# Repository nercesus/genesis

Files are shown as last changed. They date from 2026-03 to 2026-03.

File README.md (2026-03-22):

# Genesis
A 65% keyboard pcb with support for the [C3, C4, and S1 unified daughterboards](https://unified-daughterboard.github.io/).  
It also uses the [bakeneko65's](https://github.com/kkatano/bakeneko-65) outline, but don't expect it to be 100% compatible.  
This project was made back in 2022 using an older KiCad version, so some issues may come up when using a modern version.  

# layout
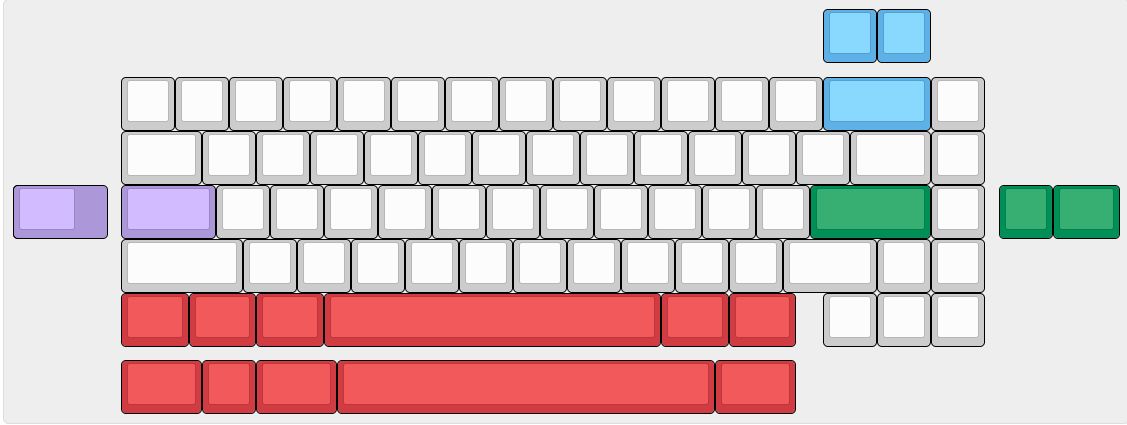
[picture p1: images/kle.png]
kle


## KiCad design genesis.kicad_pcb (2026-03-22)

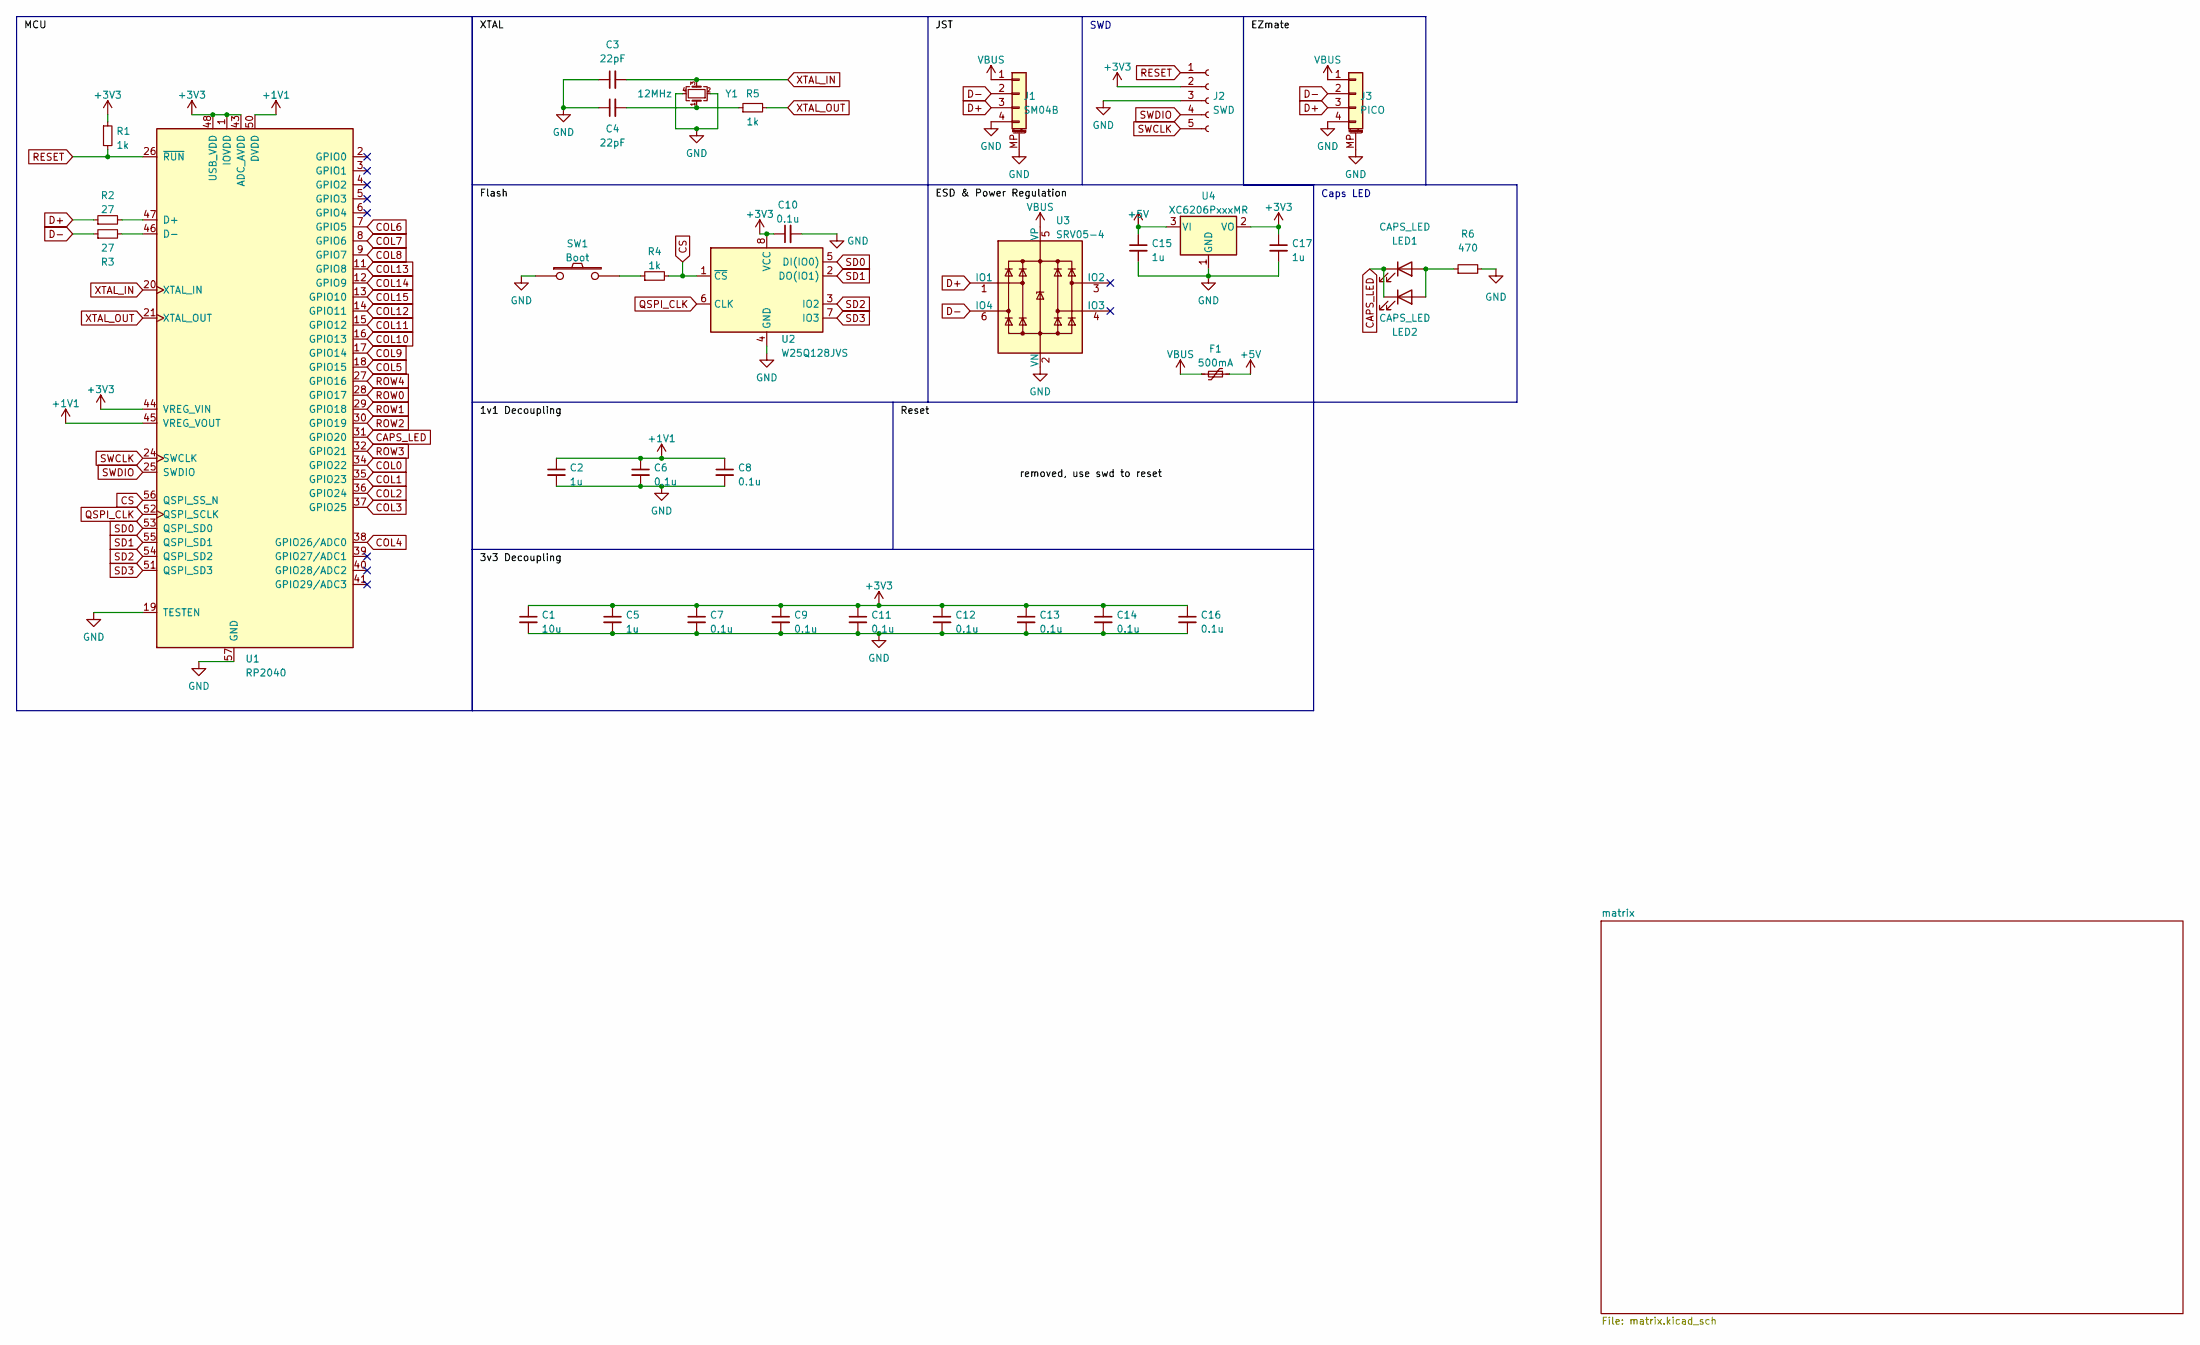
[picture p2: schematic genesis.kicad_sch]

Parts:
C1: 10u; C_0402_1005Metric
C2, C5, C15, C17: 1u; C_0402_1005Metric
C3, C4: 22pF; C_0402_1005Metric
C6, C7, C8, C9, C10, C11, C12, C13, C14, C16: 0.1u; C_0402_1005Metric
F1: 500mA; Fuse_1206_3216Metric
J1: SM04B; JST_SH_SM04B-SRSS-TB_1x04-1MP_P1.00mm_Horizontal
J2: SWD; PinSocket_1x05_P2.54mm_Vertical
J3: PICO; Molex_Pico-EZmate_78171-0004_1x04-1MP_P1.20mm_Vertical
LED1: CAPS_LED; MX-LEDONLY
LED2: CAPS_LED; MX-LEDONLY-FLIPPED
R1, R4, R5: 1k; R_0402_1005Metric
R2, R3: 27; R_0603_1608Metric
R6: 470; R_0402_1005Metric
SW1: Boot; PinHeader_1x02_P2.54mm_Vertical
U1: RP2040; RP2040-QFN-56; LCSC C2040
U2: W25Q128JVS; SOIC-8_5.23x5.23mm_P1.27mm
U3: SRV05-4; SOT-23-6-routable
U4: XC6206PxxxMR; SOT-23
Y1: 12MHz; Crystal_SMD_3225-4Pin_3.2x2.5mm

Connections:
+1V1: C2.1, C6.1, C8.1, U1.23 (DVDD), U1.45 (VREG_VOUT), U1.50 (DVDD)
+3V3: C1.1, C5.1, C7.1, C9.1, C10.1, C11.1, C12.1, C13.1, C14.1, C16.1, C17.1, J2.2, R1.1, U1.1 (IOVDD), U1.10 (IOVDD), U1.22 (IOVDD), U1.33 (IOVDD), U1.42 (IOVDD), U1.43 (ADC_AVDD), U1.44 (VREG_VIN), U1.48 (USB_VDD), U1.49 (IOVDD), U2.8 (VCC), U4.2 (VO)
+5V: C15.1, F1.1, U4.3 (VI)
CAPS_LED: LED1.1 (K), LED2.1 (K), U1.31 (GPIO20)
COL0: U1.34 (GPIO22); also elsewhere on the board
COL1: U1.35 (GPIO23); also elsewhere on the board
COL2: U1.36 (GPIO24); also elsewhere on the board
COL3: U1.37 (GPIO25); also elsewhere on the board
COL4: U1.38 (GPIO26/ADC0); also elsewhere on the board
COL5: U1.18 (GPIO15); also elsewhere on the board
COL6: U1.7 (GPIO5); also elsewhere on the board
COL7: U1.8 (GPIO6); also elsewhere on the board
COL8: U1.9 (GPIO7); also elsewhere on the board
COL9: U1.17 (GPIO14); also elsewhere on the board
COL10: U1.16 (GPIO13); also elsewhere on the board
COL11: U1.15 (GPIO12); also elsewhere on the board
COL12: U1.14 (GPIO11); also elsewhere on the board
COL13: U1.11 (GPIO8); also elsewhere on the board
COL14: U1.12 (GPIO9); also elsewhere on the board
COL15: U1.13 (GPIO10); also elsewhere on the board
CS: R4.2, U1.56 (QSPI_SS_N), U2.1 (~CS)
D+: J1.3, J3.3, R2.1, U3.1 (IO1)
D-: J1.2, J3.2, R3.1, U3.6 (IO4)
GND: C1.2, C2.2, C3.1, C4.1, C5.2, C6.2, C7.2, C8.2, C9.2, C10.2, C11.2, C12.2, C13.2, C14.2, C15.2, C16.2, C17.2, J1.4, J1.MP (MountPin), J2.3, J3.4, J3.MP (MountPin), R6.2, SW1.1, U1.19 (TESTEN), U1.57 (GND), U2.4 (GND), U3.2 (VN), U4.1 (GND), Y1.2, Y1.4
unnamed: C4.2, R5.1, Y1.1
unnamed: LED1.2 (A), LED2.2 (A), R6.1
unnamed: R2.2, U1.47 (D+)
unnamed: R3.2, U1.46 (D-)
unnamed: R4.1, SW1.2
QSPI_CLK: U1.52 (QSPI_SCLK), U2.6 (CLK)
RESET: J2.1, R1.2, U1.26 (~RUN)
ROW0: U1.28 (GPIO17); also elsewhere on the board
ROW1: U1.29 (GPIO18); also elsewhere on the board
ROW2: U1.30 (GPIO19); also elsewhere on the board
ROW3: U1.32 (GPIO21); also elsewhere on the board
ROW4: U1.27 (GPIO16); also elsewhere on the board
SD0: U1.53 (QSPI_SD0), U2.5 (DI(IO0))
SD1: U1.55 (QSPI_SD1), U2.2 (DO(IO1))
SD2: U1.54 (QSPI_SD2), U2.3 (IO2)
SD3: U1.51 (QSPI_SD3), U2.7 (IO3)
SWCLK: J2.5, U1.24 (SWCLK)
SWDIO: J2.4, U1.25 (SWDIO)
VBUS: F1.2, J1.1, J3.1, U3.5 (VP)
XTAL_IN: C3.2, U1.20 (XTAL_IN), Y1.3
XTAL_OUT: R5.2, U1.21 (XTAL_OUT)

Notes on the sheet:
SWD
Caps LED

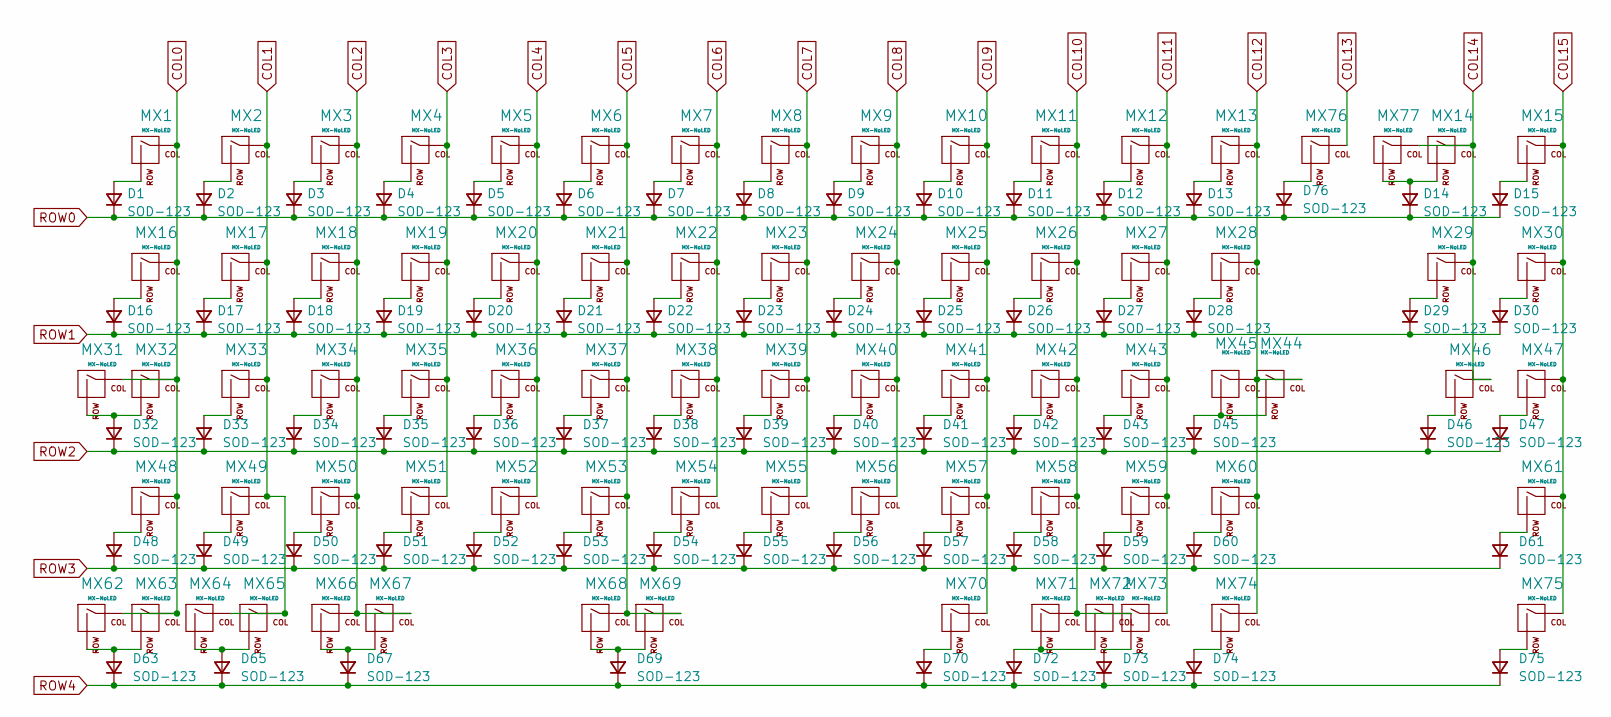
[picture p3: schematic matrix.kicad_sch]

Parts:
D1, D2, D3, D4, D5, D6, D7, D8, D9, D10, D11, D12, D13, D14, D15, D16, D17, D18, D19, D20, D21, D22, D23, D24, D25, D26, D27, D28, D29, D30, D32, D33, D34, D35, D36, D37, D38, D39, D40, D41, D42, D43, D45, D46, D47, D48, D49, D50, D51, D52, D53, D54, D55, D56, D57, D58, D59, D60, D61, D63, D65, D67, D69, D70, D72, D73, D74, D75, D76: SOD-123; D_SOD-123; LCSC C33221
MX1, MX2, MX3, MX4, MX5, MX6, MX7, MX8, MX9, MX10, MX11, MX12, MX13, MX15, MX17, MX18, MX19, MX20, MX21, MX22, MX23, MX24, MX25, MX26, MX27, MX28, MX30, MX33, MX34, MX35, MX36, MX37, MX38, MX39, MX40, MX41, MX42, MX43, MX44, MX47, MX49, MX50, MX51, MX52, MX53, MX54, MX55, MX56, MX57, MX58, MX60, MX61, MX65, MX73, MX74, MX75, MX76, MX77: MX-NoLED; MXOnly-1U-NoLED
MX14: MX-NoLED; MXOnly-2U-NoLED
MX16, MX29, MX63, MX67, MX71: MX-NoLED; MXOnly-1.5U-NoLED
MX31, MX46, MX62, MX64, MX66, MX70, MX72: MX-NoLED; MXOnly-1.25U-NoLED
MX32, MX59: MX-NoLED; MXOnly-1.75U-NoLED
MX45, MX48: MX-NoLED; MXOnly-2.25U-NoLED
MX68: MX-NoLED; MXOnly-6.25U-ReversedStabilizers-NoLED
MX69: MX-NoLED; MXOnly-7U-ReversedStabilizers-NoLED

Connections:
COL0: MX1.1 (COL), MX16.1 (COL), MX31.1 (COL), MX32.1 (COL), MX48.1 (COL), MX62.1 (COL), MX63.1 (COL); also elsewhere on the board
COL1: MX2.1 (COL), MX17.1 (COL), MX33.1 (COL), MX49.1 (COL), MX64.1 (COL), MX65.1 (COL); also elsewhere on the board
COL2: MX3.1 (COL), MX18.1 (COL), MX34.1 (COL), MX50.1 (COL), MX66.1 (COL), MX67.1 (COL); also elsewhere on the board
COL3: MX4.1 (COL), MX19.1 (COL), MX35.1 (COL), MX51.1 (COL); also elsewhere on the board
COL4: MX5.1 (COL), MX20.1 (COL), MX36.1 (COL), MX52.1 (COL); also elsewhere on the board
COL5: MX6.1 (COL), MX21.1 (COL), MX37.1 (COL), MX53.1 (COL), MX68.1 (COL), MX69.1 (COL); also elsewhere on the board
COL6: MX7.1 (COL), MX22.1 (COL), MX38.1 (COL), MX54.1 (COL); also elsewhere on the board
COL7: MX8.1 (COL), MX23.1 (COL), MX39.1 (COL), MX55.1 (COL); also elsewhere on the board
COL8: MX9.1 (COL), MX24.1 (COL), MX40.1 (COL), MX56.1 (COL); also elsewhere on the board
COL9: MX10.1 (COL), MX25.1 (COL), MX41.1 (COL), MX57.1 (COL), MX70.1 (COL); also elsewhere on the board
COL10: MX11.1 (COL), MX26.1 (COL), MX42.1 (COL), MX58.1 (COL), MX71.1 (COL), MX72.1 (COL); also elsewhere on the board
COL11: MX12.1 (COL), MX27.1 (COL), MX43.1 (COL), MX59.1 (COL), MX73.1 (COL); also elsewhere on the board
COL12: MX13.1 (COL), MX28.1 (COL), MX44.1 (COL), MX45.1 (COL), MX60.1 (COL), MX74.1 (COL); also elsewhere on the board
COL13: MX76.1 (COL); also elsewhere on the board
COL14: MX14.1 (COL), MX29.1 (COL), MX46.1 (COL), MX77.1 (COL); also elsewhere on the board
COL15: MX15.1 (COL), MX30.1 (COL), MX47.1 (COL), MX61.1 (COL), MX75.1 (COL); also elsewhere on the board
unnamed: D1.2 (A), MX1.2 (ROW)
unnamed: D2.2 (A), MX2.2 (ROW)
unnamed: D3.2 (A), MX3.2 (ROW)
unnamed: D4.2 (A), MX4.2 (ROW)
unnamed: D5.2 (A), MX5.2 (ROW)
unnamed: D6.2 (A), MX6.2 (ROW)
unnamed: D7.2 (A), MX7.2 (ROW)
unnamed: D8.2 (A), MX8.2 (ROW)
unnamed: D9.2 (A), MX9.2 (ROW)
unnamed: D10.2 (A), MX10.2 (ROW)
unnamed: D11.2 (A), MX11.2 (ROW)
unnamed: D12.2 (A), MX12.2 (ROW)
unnamed: D13.2 (A), MX13.2 (ROW)
unnamed: D14.2 (A), MX14.2 (ROW), MX77.2 (ROW)
unnamed: D15.2 (A), MX15.2 (ROW)
unnamed: D16.2 (A), MX16.2 (ROW)
unnamed: D17.2 (A), MX17.2 (ROW)
unnamed: D18.2 (A), MX18.2 (ROW)
unnamed: D19.2 (A), MX19.2 (ROW)
unnamed: D20.2 (A), MX20.2 (ROW)
unnamed: D21.2 (A), MX21.2 (ROW)
unnamed: D22.2 (A), MX22.2 (ROW)
unnamed: D23.2 (A), MX23.2 (ROW)
unnamed: D24.2 (A), MX24.2 (ROW)
unnamed: D25.2 (A), MX25.2 (ROW)
unnamed: D26.2 (A), MX26.2 (ROW)
unnamed: D27.2 (A), MX27.2 (ROW)
unnamed: D28.2 (A), MX28.2 (ROW)
unnamed: D29.2 (A), MX29.2 (ROW)
unnamed: D30.2 (A), MX30.2 (ROW)
unnamed: D32.2 (A), MX31.2 (ROW), MX32.2 (ROW)
unnamed: D33.2 (A), MX33.2 (ROW)
unnamed: D34.2 (A), MX34.2 (ROW)
unnamed: D35.2 (A), MX35.2 (ROW)
unnamed: D36.2 (A), MX36.2 (ROW)
unnamed: D37.2 (A), MX37.2 (ROW)
unnamed: D38.2 (A), MX38.2 (ROW)
unnamed: D39.2 (A), MX39.2 (ROW)
unnamed: D40.2 (A), MX40.2 (ROW)
unnamed: D41.2 (A), MX41.2 (ROW)
unnamed: D42.2 (A), MX42.2 (ROW)
unnamed: D43.2 (A), MX43.2 (ROW)
unnamed: D45.2 (A), MX44.2 (ROW), MX45.2 (ROW)
unnamed: D46.2 (A), MX46.2 (ROW)
unnamed: D47.2 (A), MX47.2 (ROW)
unnamed: D48.2 (A), MX48.2 (ROW)
unnamed: D49.2 (A), MX49.2 (ROW)
unnamed: D50.2 (A), MX50.2 (ROW)
unnamed: D51.2 (A), MX51.2 (ROW)
unnamed: D52.2 (A), MX52.2 (ROW)
unnamed: D53.2 (A), MX53.2 (ROW)
unnamed: D54.2 (A), MX54.2 (ROW)
unnamed: D55.2 (A), MX55.2 (ROW)
unnamed: D56.2 (A), MX56.2 (ROW)
unnamed: D57.2 (A), MX57.2 (ROW)
unnamed: D58.2 (A), MX58.2 (ROW)
unnamed: D59.2 (A), MX59.2 (ROW)
unnamed: D60.2 (A), MX60.2 (ROW)
unnamed: D61.2 (A), MX61.2 (ROW)
unnamed: D63.2 (A), MX62.2 (ROW), MX63.2 (ROW)
unnamed: D65.2 (A), MX64.2 (ROW), MX65.2 (ROW)
unnamed: D67.2 (A), MX66.2 (ROW), MX67.2 (ROW)
unnamed: D69.2 (A), MX68.2 (ROW), MX69.2 (ROW)
unnamed: D70.2 (A), MX70.2 (ROW)
unnamed: D72.2 (A), MX71.2 (ROW), MX72.2 (ROW)
unnamed: D73.2 (A), MX73.2 (ROW)
unnamed: D74.2 (A), MX74.2 (ROW)
unnamed: D75.2 (A), MX75.2 (ROW)
unnamed: D76.2 (A), MX76.2 (ROW)
ROW0: D1.1 (K), D2.1 (K), D3.1 (K), D4.1 (K), D5.1 (K), D6.1 (K), D7.1 (K), D8.1 (K), D9.1 (K), D10.1 (K), D11.1 (K), D12.1 (K), D13.1 (K), D14.1 (K), D15.1 (K), D76.1 (K); also elsewhere on the board
ROW1: D16.1 (K), D17.1 (K), D18.1 (K), D19.1 (K), D20.1 (K), D21.1 (K), D22.1 (K), D23.1 (K), D24.1 (K), D25.1 (K), D26.1 (K), D27.1 (K), D28.1 (K), D29.1 (K), D30.1 (K); also elsewhere on the board
ROW2: D32.1 (K), D33.1 (K), D34.1 (K), D35.1 (K), D36.1 (K), D37.1 (K), D38.1 (K), D39.1 (K), D40.1 (K), D41.1 (K), D42.1 (K), D43.1 (K), D45.1 (K), D46.1 (K), D47.1 (K); also elsewhere on the board
ROW3: D48.1 (K), D49.1 (K), D50.1 (K), D51.1 (K), D52.1 (K), D53.1 (K), D54.1 (K), D55.1 (K), D56.1 (K), D57.1 (K), D58.1 (K), D59.1 (K), D60.1 (K), D61.1 (K); also elsewhere on the board
ROW4: D63.1 (K), D65.1 (K), D67.1 (K), D69.1 (K), D70.1 (K), D72.1 (K), D73.1 (K), D74.1 (K), D75.1 (K); also elsewhere on the board

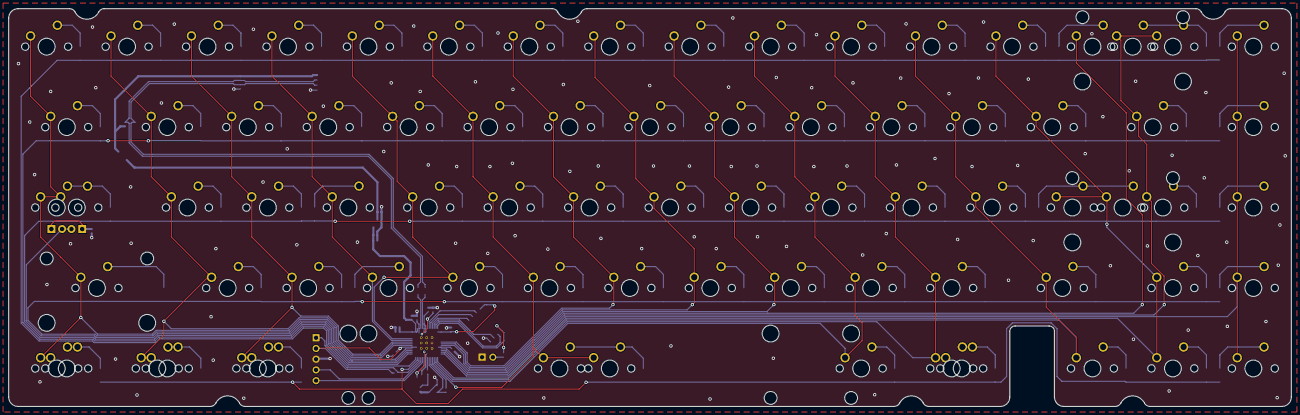
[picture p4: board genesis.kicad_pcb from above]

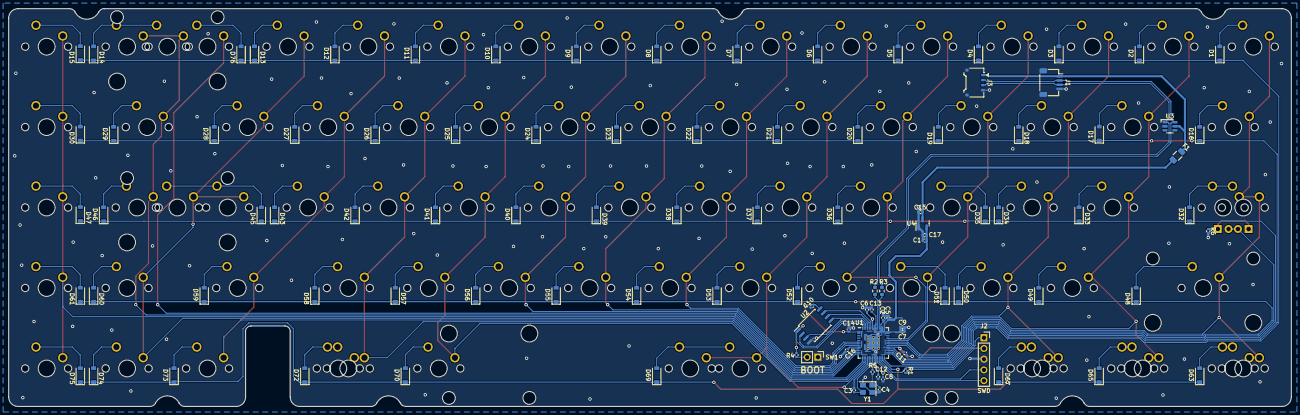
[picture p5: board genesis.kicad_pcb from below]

Board: 2 copper layers, 303.8 x 94.2 mm, 181 parts (102 on the bottom side), 114 nets.
